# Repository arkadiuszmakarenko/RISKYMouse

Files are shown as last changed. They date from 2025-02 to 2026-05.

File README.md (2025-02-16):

# RISKYMouse
RISKYMouse - Amiga DB9 - USB Hid Mouse Adapter

## Acknowledgments
Project is based on following projects:

 * Mist (USB HID parser stack)
 * Mouse Driver - sq7bti.
 * Simon Inns smallymouse2 mouse quadrature encoding

## PCB Project
This project does't provide PCB design, only schematics. You are free to design your own based on schematics provided.
You can use RISKYKVM as PCB design as those two projects are pin compatible.

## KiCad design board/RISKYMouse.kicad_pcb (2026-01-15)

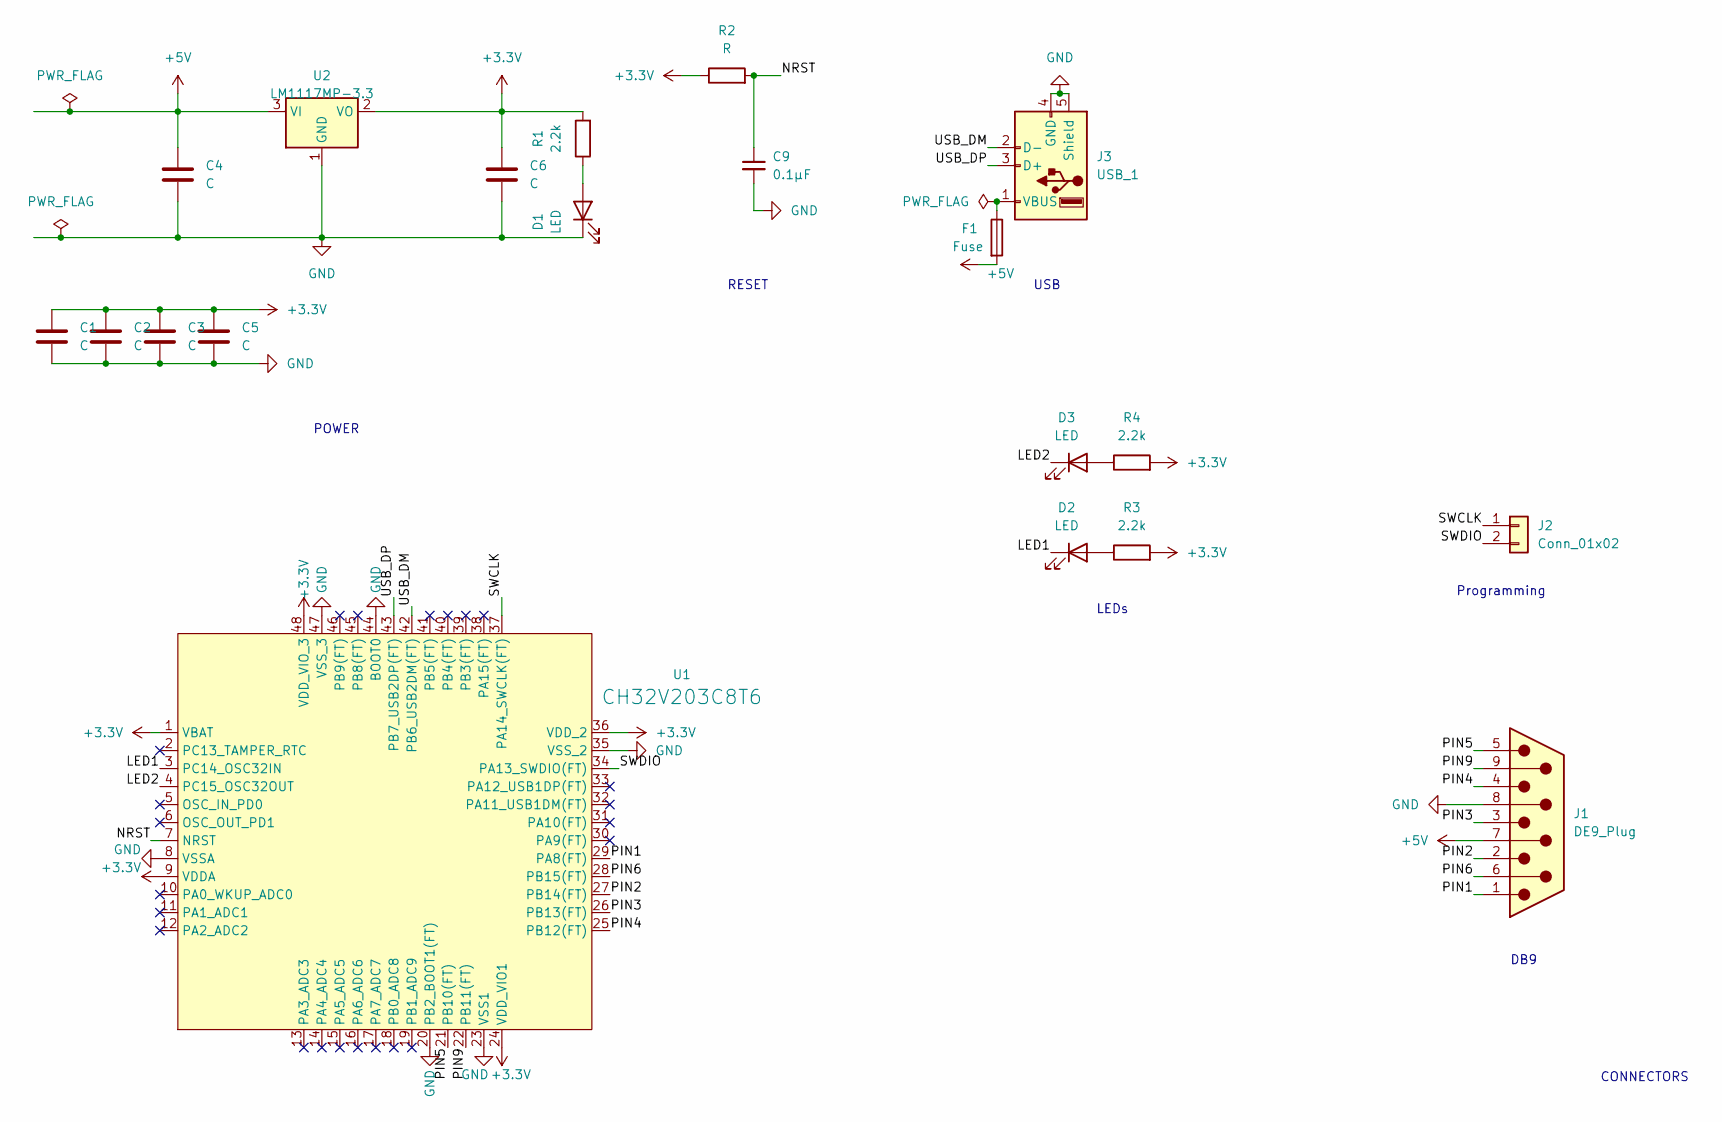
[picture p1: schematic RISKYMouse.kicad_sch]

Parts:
C1, C2, C3, C4, C5, C6: C; C_0603_1608Metric_Pad1.08x0.95mm_HandSolder
C9: 0.1μF; C_0603_1608Metric_Pad1.08x0.95mm_HandSolder; LCSC C14663
D1, D2, D3: LED; LED_0805_2012Metric_Pad1.15x1.40mm_HandSolder
F1: Fuse; Fuse_1206_3216Metric_Pad1.42x1.75mm_HandSolder
J1: DE9_Plug; DSUB-9_Female_EdgeMount_P2.77mm
J2: Conn_01x02; PinHeader_1x02_P2.54mm_Vertical
J3: USB_1; USB_A_CONNFLY_DS1095-WNR0
R1, R3, R4: 2.2k; R_0603_1608Metric_Pad0.98x0.95mm_HandSolder
R2: R; R_0603_1608Metric_Pad0.98x0.95mm_HandSolder
U1: CH32V203C8T6; LQFP-48_7x7mm_P0.5mm
U2: LM1117MP-3.3; SOT-89-3

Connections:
+3.3V: C1.1, C2.1, C3.1, C5.1, C6.1, R1.2, R2.1, R3.2, R4.2, U1.1 (VBAT), U1.9 (VDDA), U1.24 (VDD_VIO1), U1.36 (VDD_2), U1.48 (VDD_VIO_3), U2.2 (VO)
+5V: C4.1, F1.2, J1.7, U2.3 (VI)
/LED1: D2.1 (K), U1.3 (PC14_OSC32IN)
/LED2: D3.1 (K), U1.4 (PC15_OSC32OUT)
/NRST: C9.1, R2.2, U1.7 (NRST)
/PIN1: J1.1, U1.29 (PA8(FT))
/PIN2: J1.2, U1.27 (PB14(FT))
/PIN3: J1.3, U1.26 (PB13(FT))
/PIN4: J1.4, U1.25 (PB12(FT))
/PIN5: J1.5, U1.21 (PB10(FT))
/PIN6: J1.6, U1.28 (PB15(FT))
/PIN9: J1.9, U1.22 (PB11(FT))
/SWCLK: J2.1, U1.37 (PA14_SWCLK(FT))
/SWDIO: J2.2, U1.34 (PA13_SWDIO(FT))
/USB_DM: J3.2 (D-), U1.42 (PB6_USB2DM(FT))
/USB_DP: J3.3 (D+), U1.43 (PB7_USB2DP(FT))
GND: C1.2, C2.2, C3.2, C4.2, C5.2, C6.2, C9.2, D1.1 (K), J1.8, J3.4 (GND), J3.5 (Shield), U1.8 (VSSA), U1.20 (PB2_BOOT1(FT)), U1.23 (VSS1), U1.35 (VSS_2), U1.44 (BOOT0), U1.47 (VSS_3), U2.1 (GND)
unnamed: D1.2 (A), R1.1
unnamed: D2.2 (A), R3.1
unnamed: D3.2 (A), R4.1
unnamed: F1.1, J3.1 (VBUS)

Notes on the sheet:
USB
LEDs
Programming
POWER
CONNECTORS
DB9
RESET

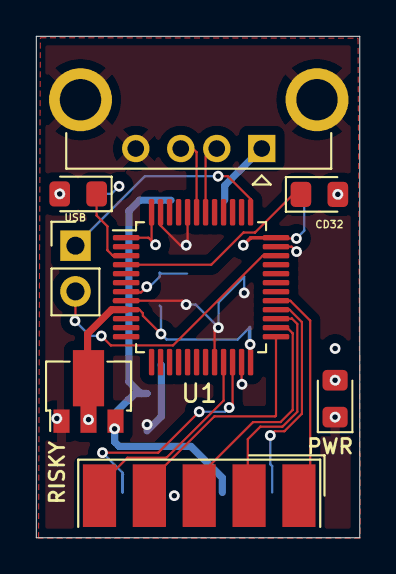
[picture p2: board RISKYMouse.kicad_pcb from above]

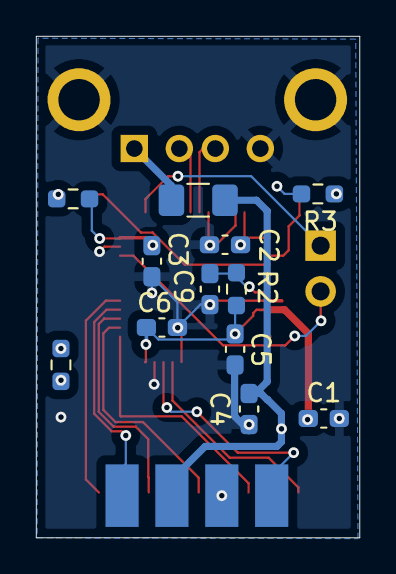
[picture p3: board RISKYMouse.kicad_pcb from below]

Board: 4 copper layers, 18.0 x 27.9 mm, 20 parts (12 on the bottom side), 21 nets.

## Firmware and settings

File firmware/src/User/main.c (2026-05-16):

#include <usb_gamepad.h>
#include <usb_mouse.h>
#include "usb_host_config.h"
#include "utils.h"
#include "tim.h"
#include "mouse.h"
#include "gpio.h"
#include "gamepad.h"

int main (void) {
    DUG_PRINTF ("SystemClk:%d\r\n", SystemCoreClock);
    Delay_Init();
    TIM3_Init (9, SystemCoreClock / 10000 - 1);

#if DEF_USBFS_PORT_EN
    USBFS_RCC_Init();
    USBFS_Host_Init (ENABLE);
    memset (&RootHubDev.bStatus, 0, sizeof (ROOT_HUB_DEVICE));
    memset (&HostCtl[DEF_USBFS_PORT_INDEX * DEF_ONE_USB_SUP_DEV_TOTAL].InterfaceNum, 0, DEF_ONE_USB_SUP_DEV_TOTAL * sizeof (HOST_CTL));
#endif

    TIM2_Init();
    TIM4_Init();
    GPIO_Config();
    InitMouse();

    while (1) {
        USBH_MainDeal();
        // Handle HID/Xbox root device
        if ((RootHubDev.bType == USB_DEV_CLASS_HID) || (RootHubDev.bType == DEF_DEV_TYPE_XBOX360)) {

            for (int itf = 0; itf < DEF_INTERFACE_NUM_MAX; itf++) {
                // Handle mouse
                if (HostCtl[0].Interface[itf].HIDRptDesc.type == REPORT_TYPE_MOUSE) {
                    HID_MOUSE_Data *mousemap = USB_GetMouseInfo (
                        &HostCtl[0].Interface[itf]);
                    ProcessMouse (mousemap);
                }

                if ((HostCtl[0].Interface[itf].HIDRptDesc.type == REPORT_TYPE_JOYSTICK) || (HostCtl[0].Interface[itf].Type == DEC_XBOX360)) {

                    HID_gamepad_Info_TypeDef *gamepad = GetGamepadInfo (
                        &HostCtl[0].Interface[itf]);
                    ProcessGamepad (gamepad);
                }
            }
        }

        // Handle HUB Device

        if (RootHubDev.bType == USB_DEV_CLASS_HUB) {

            // Iterate over all devices
            for (uint8_t device = 1; device < 5; device++) {
                // Iterate over all interfaces
                for (int itf = 0; itf < DEF_INTERFACE_NUM_MAX; itf++) {

                    // Handle mouse
                    if (HostCtl[device].Interface[itf].HIDRptDesc.type == REPORT_TYPE_MOUSE) {
                        HID_MOUSE_Data *mousemap = USB_GetMouseInfo (
                            &HostCtl[device].Interface[itf]);
                        ProcessMouse (mousemap);
                    }

                    if ((HostCtl[device].Interface[itf].HIDRptDesc.type == REPORT_TYPE_JOYSTICK) || (HostCtl[device].Interface[itf].Type == DEC_XBOX360)) {

                        HID_gamepad_Info_TypeDef *gamepad = GetGamepadInfo (
                            &HostCtl[device].Interface[itf]);
                        ProcessGamepad (gamepad);
                    }
                }
            }
        }
    }
}

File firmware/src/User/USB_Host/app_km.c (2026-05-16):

/********************************** (C) COPYRIGHT  *******************************
 * File Name          : app_km.c
 * Author             : WCH
 * Version            : V1.0.0
 * Date               : 2022/09/01
 * Description        : The USB host operates the keyboard and mouse.
*********************************************************************************
* Copyright (c) 2021 Nanjing Qinheng Microelectronics Co., Ltd.
* Attention: This software (modified or not) and binary are used for 
* microcontroller manufactured by Nanjing Qinheng Microelectronics.
*******************************************************************************/


/********************************************************************************/
/* Header File */
#include "usb_host_config.h"
#include "gpio.h"

#define DEF_XBOX360_VID                 0x045E
#define DEF_XBOX360_PID                 0x028E
#define DEF_XBOX360_ITF_CLASS           0xFF
#define DEF_XBOX360_ITF_SUBCLASS        0x5D
#define DEF_XBOX360_ITF_PROTOCOL        0x01

/*******************************************************************************/
/* Variable Definition */
uint8_t  DevDesc_Buf[ 18 ];                                                     // Device Descriptor Buffer
uint8_t  Com_Buf[ DEF_COM_BUF_LEN ];                                            // General Buffer
struct   _ROOT_HUB_DEVICE RootHubDev;
struct   __HOST_CTL HostCtl[ DEF_TOTAL_ROOT_HUB * DEF_ONE_USB_SUP_DEV_TOTAL ];

/*******************************************************************************/
/* Interrupt Function Declaration */
void TIM3_IRQHandler(void) __attribute__((interrupt("WCH-Interrupt-fast")));

/*********************************************************************
 * @fn      TIM3_Init
 *
 * @brief   Initialize timer3 for getting keyboard and mouse data.
 *
 * @param   arr - The specific period value.
 *          psc - The specifies prescaler value.
 *
 * @return  none
 */
void TIM3_Init( uint16_t arr, uint16_t psc )
{
    TIM_TimeBaseInitTypeDef TIM_TimeBaseStructure = { 0 };
    NVIC_InitTypeDef NVIC_InitStructure = { 0 };

    /* Enable timer3 clock */
    RCC_APB1PeriphClockCmd( RCC_APB1Periph_TIM3, ENABLE );

    /* Initialize timer3 */
    TIM_TimeBaseStructure.TIM_Period = arr;
    TIM_TimeBaseStructure.TIM_Prescaler = psc;
    TIM_TimeBaseStructure.TIM_ClockDivision = TIM_CKD_DIV1;
    TIM_TimeBaseStructure.TIM_CounterMode = TIM_CounterMode_Up;
    TIM_TimeBaseInit( TIM3, &TIM_TimeBaseStructure );

    /* Enable updating timer3 interrupt */
    TIM_ITConfig( TIM3, TIM_IT_Update, ENABLE );

    /* Configure timer3 interrupt */
    NVIC_InitStructure.NVIC_IRQChannel = TIM3_IRQn;
    NVIC_InitStructure.NVIC_IRQChannelPreemptionPriority = 1;
    NVIC_InitStructure.NVIC_IRQChannelSubPriority = 2;
    NVIC_InitStructure.NVIC_IRQChannelCmd = ENABLE;
    NVIC_Init( &NVIC_InitStructure );

    /* Enable timer3 */
    TIM_Cmd( TIM3, ENABLE );

    /* Enable timer3 interrupt */
    NVIC_EnableIRQ( TIM3_IRQn );
}

/*********************************************************************
 * @fn      TIM3_IRQHandler
 *
 * @brief   This function handles TIM3 global interrupt request.
 *
 * @return  none
 */
void TIM3_IRQHandler( void )
{
    uint8_t index;
    uint8_t hub_port;
    uint8_t intf_num, in_num;

    if( TIM_GetITStatus( TIM3, TIM_IT_Update ) != RESET )
    {
        /* Clear interrupt flag */
        TIM_ClearITPendingBit( TIM3, TIM_IT_Update );

        /* USB HID/Xbox Device Input Endpoint Timing */
        if( RootHubDev.bStatus >= ROOT_DEV_SUCCESS )
        {
            index = RootHubDev.DeviceIndex;
            if( ( RootHubDev.bType == USB_DEV_CLASS_HID ) || ( RootHubDev.bType == DEF_DEV_TYPE_XBOX360 ) )
            {
                for( intf_num = 0; intf_num < HostCtl[ index ].InterfaceNum; intf_num++ )
                {
                    for( in_num = 0; in_num < HostCtl[ index ].Interface[ intf_num ].InEndpNum; in_num++ )
                    {
                        HostCtl[ index ].Interface[ intf_num ].InEndpTimeCount[ in_num ]++;
                    }
                }
            }
            else if( RootHubDev.bType == USB_DEV_CLASS_HUB )
            {
                HostCtl[ index ].Interface[ 0 ].InEndpTimeCount[ 0 ]++;
                for( hub_port = 0; hub_port < RootHubDev.bPortNum; hub_port++ )
                {
                    if( RootHubDev.Device[ hub_port ].bStatus >= ROOT_DEV_SUCCESS )
                    {
                        index = RootHubDev.Device[ hub_port ].DeviceIndex;

                        if( ( RootHubDev.Device[ hub_port ].bType == USB_DEV_CLASS_HID ) || ( RootHubDev.Device[ hub_port ].bType == DEF_DEV_TYPE_XBOX360 ) )
                        {
                            for( intf_num = 0; intf_num < HostCtl[ index ].InterfaceNum; intf_num++ )
                            {
                                for( in_num = 0; in_num < HostCtl[ index ].Interface[ intf_num ].InEndpNum; in_num++ )
                                {
                                    HostCtl[ index ].Interface[ intf_num ].InEndpTimeCount[ in_num ]++;
                                }
                            }
                        }
                    }
                }
            }
        }
    }
}
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

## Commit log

2025-02-15 Release v0.1
    [RiskyMouse.kicad_pcb, RiskyMouse.kicad_sch]
2026-01-12 New PCB design
    [RISKYMouse.kicad_pcb, RISKYMouse.kicad_sch, RiskyMouse.kicad_pcb]
2026-01-15 revised PCB
    [RISKYMouse.kicad_pcb]
